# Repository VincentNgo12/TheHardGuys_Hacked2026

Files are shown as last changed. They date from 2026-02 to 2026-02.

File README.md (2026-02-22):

# NEST — Nursing Environment & Safety Tracker
### Smart Health Wristwatch

NEST is a **low-power ESP32 wristwatch prototype** designed for older adults or people that does not have the ability to take care of themselves.  
It helps users feel **safer, more comfortable, and more independent** by making key wellness and environment signals easy to check at a glance—without complicated menus or medical jargon.

**Our goal:** a reliable, power-efficient, hackathon-ready prototype with clean architecture and scalable code structure.

---

## Overview
This repository contains the **firmware and hardware design files** for our ESP32-based health + comfort wristwatch prototype.

**The system integrates:**
- **ESP32** (main MCU, low-power capable)
- **MAX30102** (heart rate / pulse sensing)
- **ENS160 + AHT21** (air quality + temperature + humidity)
- **MPU-6500** (motion sensing)
- **TFT LCD** (watch UI)

Firmware is built using the **Arduino framework**, but structured like a real embedded project:
- **Modular driver architecture** (each sensor isolated)
- **Cooperative FreeRTOS-style task design** (sensor polling, UI updates, Bluetooth, power management)

---

## High-level idea
NEST provides two kinds of awareness:

### 1) Health awareness
- Quick, on-demand **heart-rate checks** (simple “tap to check” experience)

### 2) Comfort awareness
- Indoor **temperature + humidity**
- **Air quality trends** (eCO2 / TVOC-style indicators)

**Design philosophy:** reassurance without overwhelm  
- big text, minimal taps  
- friendly labels + icons  
- clear prompts like: *“All good”*, *“Room feels stuffy”*, *“Take a break”*  
- optional gentle alerts (vibration) instead of loud alarms  

---

## System architecture (high-level)
NEST is organized as a clean pipeline so the UI stays responsive while keeping power low:

**Sensors → Drivers → Tasks/Scheduler → UI + Alerts → (Optional) Bluetooth**

A simple mental model:

| Layer | Components | Output |
|---|---|---|
| Sensors | MAX30102 • ENS160 + AHT21 • MPU-6500 | Raw readings |
| Driver Layer (modular) | Separate drivers per sensor | Standardized data |
| Task / Timing Layer | Polling • smoothing • thresholds • scheduling | Latest “status” + values |
| UI / Alerts | TFT Watch UI • Alerts/Bluetooth | On-screen info + vibration/summaries |

---

## Core concepts
### 1) Power-first behavior
NEST is designed around quick “check-ins”:
- measure briefly
- update the screen
- return to low-power mode whenever possible

A simple way to think about average power is:
\[
P_{\text{avg}} \approx \frac{P_{\text{active}}\,t_{\text{active}} + P_{\text{sleep}}\,t_{\text{sleep}}}{t_{\text{active}} + t_{\text{sleep}}}
\]
So the main strategy is keeping **\(t_{\text{active}}\)** short and spending most time sleeping.

### 2) Modular drivers
Each sensor is isolated in its own component so the project stays:
- easier to debug
- easier to test
- easier to expand later

### 3) Cooperative task design
Even when using Arduino, the project is structured to behave like a real embedded system:
- sensor reading doesn’t block UI updates  
- timing is predictable  
- Bluetooth/power management can be added cleanly  

---

## Repo structure
High-level folders (as included in this repository):
- `firmware/` — ESP32 firmware (Arduino-based, modular, task-oriented)
- `hardware/` — hardware design files (PCB / wiring / docs)
- `README.md` — this document

---

## Quick start (edit to match your setup)
1. Open `firmware/` in **Platform IO** 
2. Install required libraries for the display + sensors.
3. Select your ESP32 board, connect over USB, then **flash**.
4. Verify: UI boots, sensors respond, and readings update.

---

## Credits
**Team: The Hard Guys**  
- Vincent Ngo: damduchu@ualberta.ca
- Joao Pedro Assis Leitao: assislei@ualberta.ca
- Luu Gregory Nguyen: luugrego@ualberta.ca
- Jishnu Khanna: jkhanna@ualberta.ca
- Finhas Tadesse: finhas@ualberta.ca

Special thanks:
- UofA CompE club for organizing this amazing Hackathon
- Open-source libraries and community resources

---

## Disclaimer
NEST is a **hackathon prototype** intended for wellness/comfort awareness and is **not a medical device**.

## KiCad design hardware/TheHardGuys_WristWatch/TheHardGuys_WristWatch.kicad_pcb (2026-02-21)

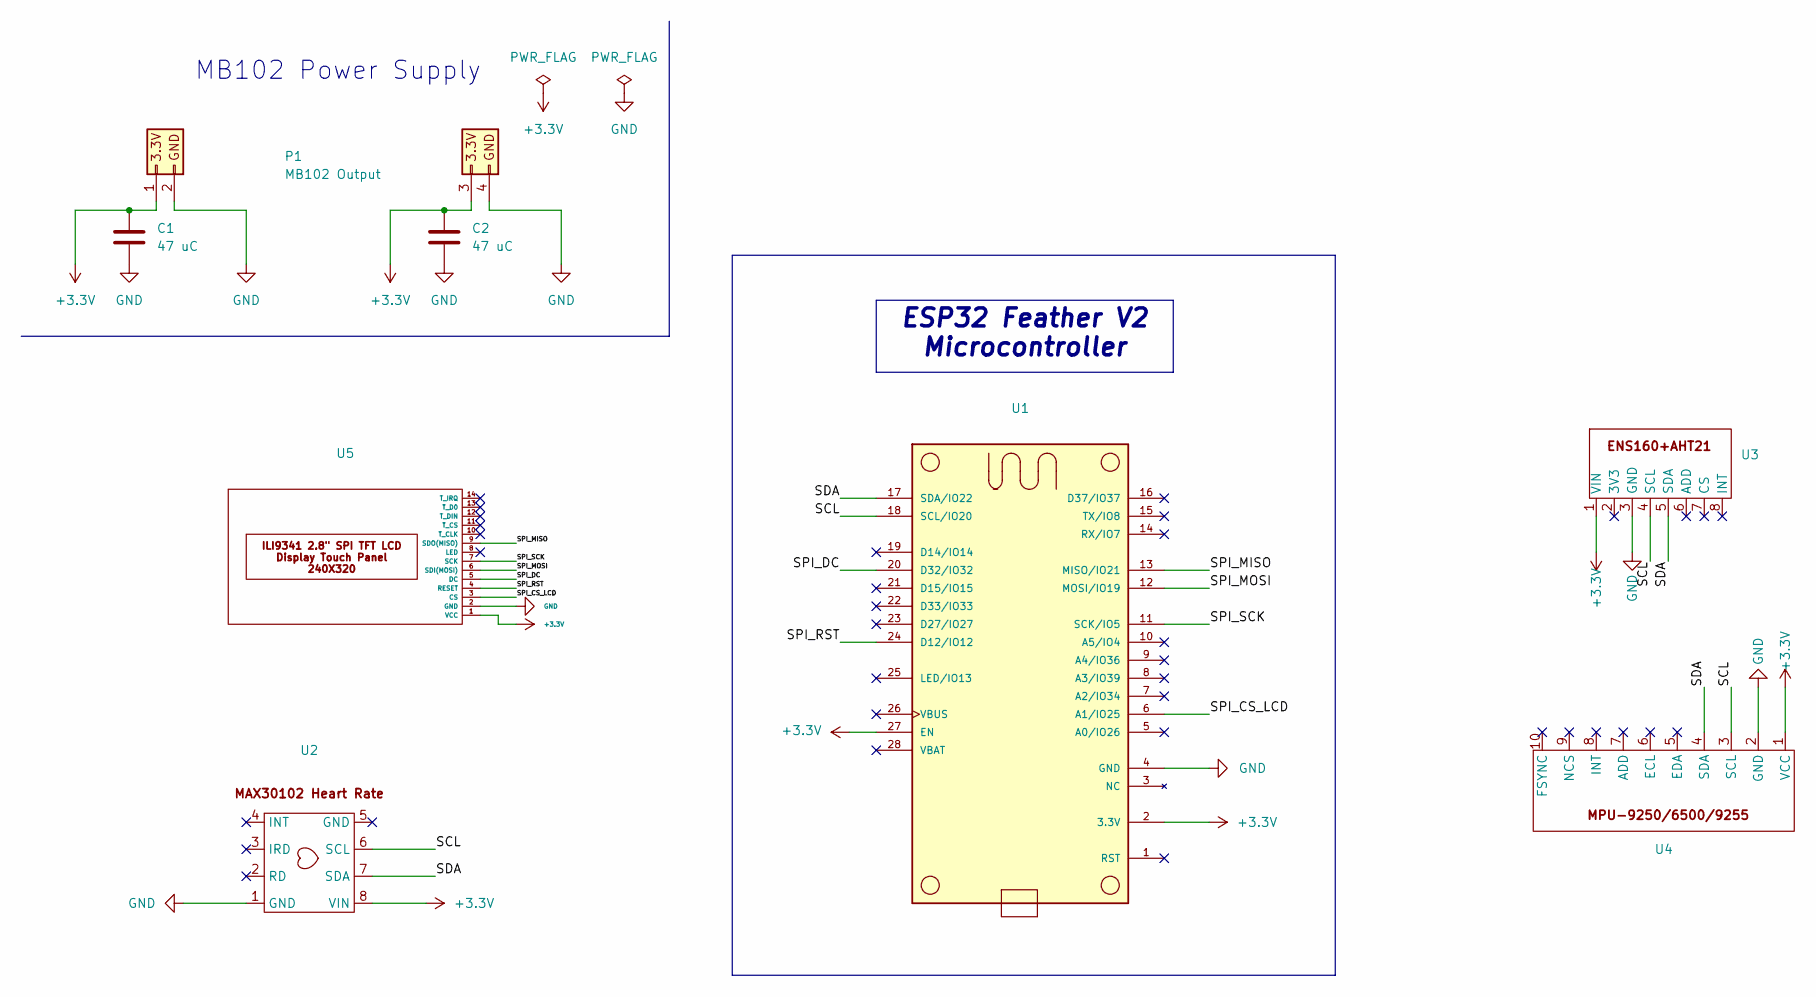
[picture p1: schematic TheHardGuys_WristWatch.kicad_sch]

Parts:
C1, C2: 47 uC; CP_Radial_D6.3mm_P2.50mm
P1: MB102 Output; MB102_Breadboard_Power_Module
U1: ESP32_Feather_V2
U2: MAX30102 Heart Rate_Pulse Sensor
U3: ENS160+AHT21_Environmental_Sensor
U4: MPU6500_IMU
U5: ILI9341_2.8__SPI_TFT_LCD

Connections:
+3.3V: C1.1, C2.1, P1.1 (3.3V), P1.3 (3.3V), U1.2 (3.3V), U1.27 (EN), U2.8 (VIN), U3.1 (VIN), U4.1 (VCC), U5.1 (VCC)
/SCL: U1.18 (SCL/IO20), U2.6 (SCL), U3.4 (SCL), U4.3 (SCL)
/SDA: U1.17 (SDA/IO22), U2.7 (SDA), U3.5 (SDA), U4.4 (SDA)
/SPI_CS_LCD: U1.6 (A1/IO25), U5.3 (CS)
/SPI_DC: U1.20 (D32/IO32), U5.5 (DC)
/SPI_MISO: U1.13 (MISO/IO21), U5.9 (SDO(MISO))
/SPI_MOSI: U1.12 (MOSI/IO19), U5.6 (SDI(MOSI))
/SPI_RST: U1.24 (D12/IO12), U5.4 (RESET)
/SPI_SCK: U1.11 (SCK/IO5), U5.7 (SCK)
GND: C1.2, C2.2, P1.2 (GND), P1.4 (GND), U1.4 (GND), U2.1 (GND), U3.3 (GND), U4.2 (GND), U5.2 (GND)

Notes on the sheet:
MB102 Power Supply
ESP32 Feather V2 Microcontroller

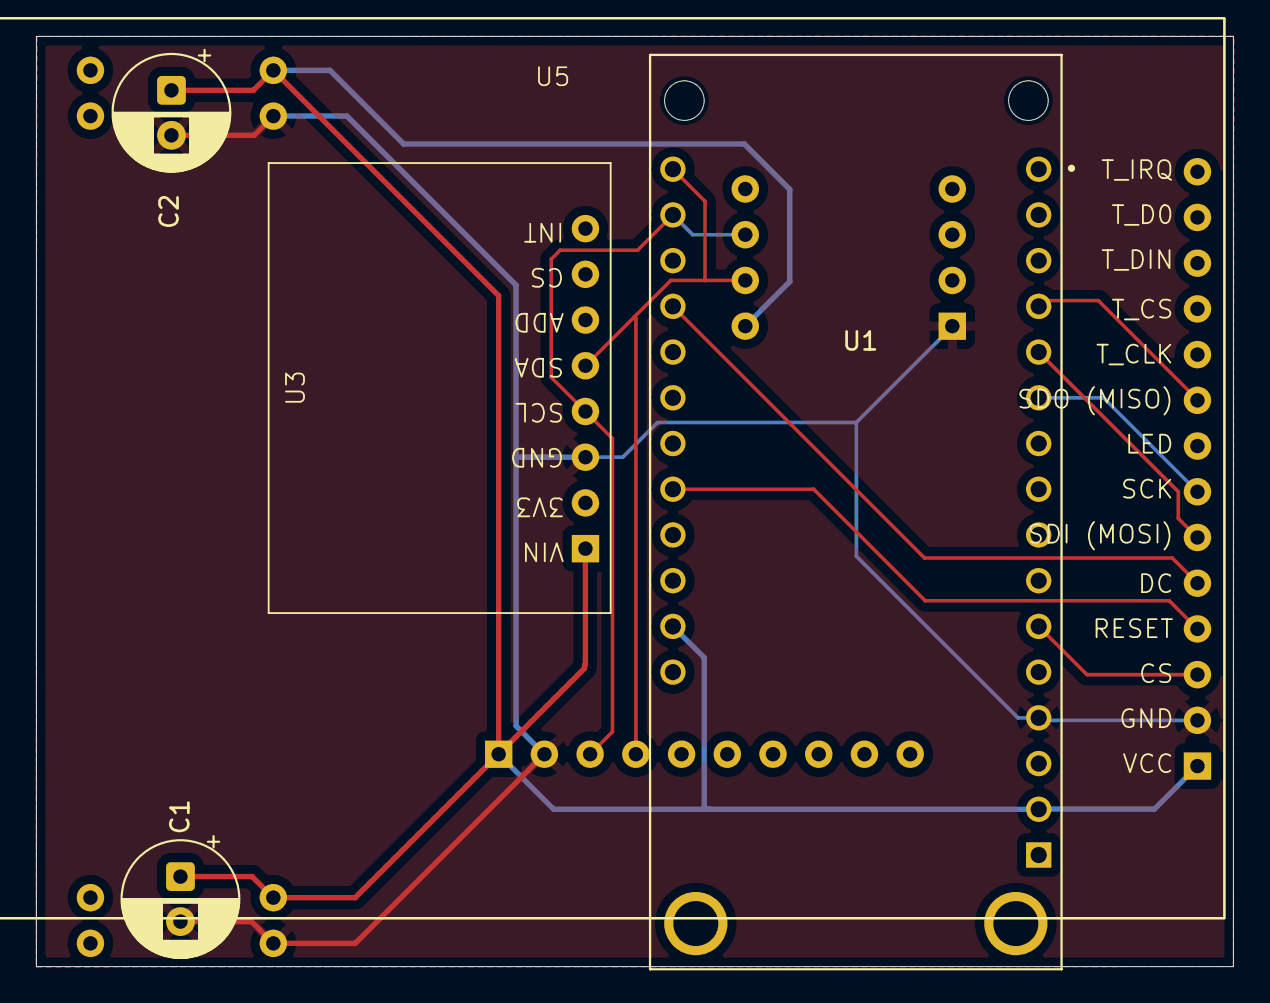
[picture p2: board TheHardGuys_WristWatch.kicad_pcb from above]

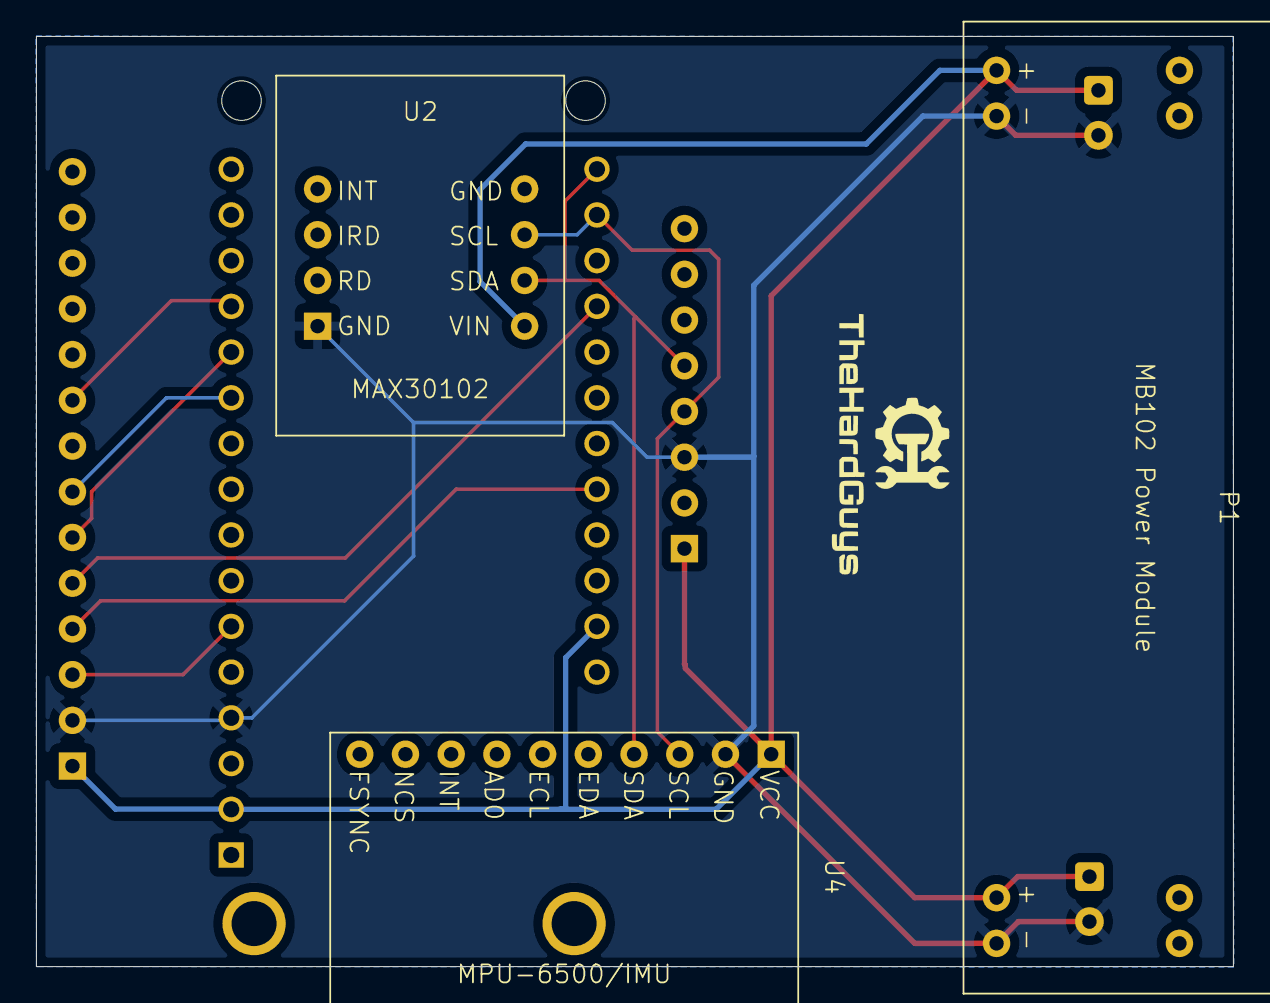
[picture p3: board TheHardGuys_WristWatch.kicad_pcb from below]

Board: 2 copper layers, 66.5 x 51.7 mm, 8 parts (3 on the bottom side), 10 nets.

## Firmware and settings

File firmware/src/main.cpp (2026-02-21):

// src/main.cpp
#include <Arduino.h>
#include <Wire.h>
#include "task_sensor.h"
#include "task_display.h"


void setup() {
    Serial.begin(115200);

    delay(2000); // extra settle time for serial debug only (remove in production code)

    Wire.begin(22, 20); // ESP32 Feather V2: SDA=22, SCL=20

    if (!sensorInit()) {
        Serial.println("Sensor init failed! Halting.");
        while (1);
    }

    Serial.println("All sensors initialized. Starting tasks...");

    if (!displayInit()) {
        Serial.println("Display init failed! Halting.");
        while (1);
    }

    Serial.println("=== All systems go ===");
}

void loop() {
    vTaskDelete(NULL);
}

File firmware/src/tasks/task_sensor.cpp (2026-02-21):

#include "task_sensor.h"
#include <Arduino.h>

// --------------------------------------------------
// Globals
// --------------------------------------------------
SensorData        g_sensorData = {};
SemaphoreHandle_t g_dataMutex  = nullptr;
SemaphoreHandle_t g_i2cMutex   = nullptr;

static AHT21Driver   aht21;
static ENS160Driver  ens160;
static MAX30102Driver max30102;
static MPU6500Driver mpu6500;

// --------------------------------------------------
// Forward declarations
// --------------------------------------------------
static void aht21Task   (void *pvParameters);
static void ens160Task  (void *pvParameters);
static void max30102Task(void *pvParameters);
static void mpu6500Task (void *pvParameters);

// --------------------------------------------------
// sensorInit — init all sensors + launch all tasks
// --------------------------------------------------
bool sensorInit() {
    g_dataMutex = xSemaphoreCreateMutex();
    g_i2cMutex  = xSemaphoreCreateMutex();

    if (!g_dataMutex || !g_i2cMutex) {
        Serial.println("[Sensor] Failed to create mutexes!");
        return false;
    }

    if (!aht21.begin()) {
        Serial.println("[Sensor] AHT21 not found!");
        return false;
    }
    Serial.println("[Sensor] AHT21 ready.");

    if (!ens160.begin()) {
        Serial.println("[Sensor] ENS160 not found!");
        return false;
    }
    Serial.println("[Sensor] ENS160 ready. Warming up...");

    if (!max30102.begin()) {
        Serial.println("[Sensor] MAX30102 not found!");
        return false;
    }
    Serial.println("[Sensor] MAX30102 ready.");

    if (!mpu6500.begin()) {
        Serial.println("[Sensor] MPU6500 not found!");
        return false;
    }
    Serial.println("[Sensor] MPU6500 ready.");

    // Launch all tasks here — main.cpp stays clean
    xTaskCreate(aht21Task,    "AHT21",    2048, NULL, 1, NULL);
    xTaskCreate(ens160Task,   "ENS160",   2048, NULL, 1, NULL);
    xTaskCreate(max30102Task, "MAX30102", 4096, NULL, 1, NULL); // larger stack, signal processing heavy
    xTaskCreate(mpu6500Task,  "MPU6500",  2048, NULL, 1, NULL);

    return true;
}

// --------------------------------------------------
// AHT21 Task — temp + humidity every 2s
// --------------------------------------------------
static void aht21Task(void *pvParameters) {
    while (true) {
        float temp, hum;

        if (xSemaphoreTake(g_i2cMutex, pdMS_TO_TICKS(500)) == pdTRUE) {
            bool ok = aht21.read(temp, hum);
            xSemaphoreGive(g_i2cMutex);

            if (ok) {
                if (xSemaphoreTake(g_dataMutex, pdMS_TO_TICKS(100)) == pdTRUE) {
                    g_sensorData.temperature = temp;
                    g_sensorData.humidity    = hum;
                    xSemaphoreGive(g_dataMutex);
                }
            } else {
                Serial.println("[AHT21] Read failed.");
            }
        }

        vTaskDelay(pdMS_TO_TICKS(2000));
    }
}

// --------------------------------------------------
// ENS160 Task — air quality every 2s
// Uses AHT21 temp+humidity for compensation
// --------------------------------------------------
static void ens160Task(void *pvParameters) {
    while (true) {
        // Grab latest AHT21 data for compensation
        float temp, hum;
        if (xSemaphoreTake(g_dataMutex, pdMS_TO_TICKS(100)) == pdTRUE) {
            temp = g_sensorData.temperature;
            hum  = g_sensorData.humidity;
            xSemaphoreGive(g_dataMutex);
        }

        uint16_t eco2, tvoc;
        int8_t   aqi;

        if (xSemaphoreTake(g_i2cMutex, pdMS_TO_TICKS(500)) == pdTRUE) {
            ens160.setCompensation(temp, hum);
            bool ok = ens160.read(eco2, tvoc, aqi);
            xSemaphoreGive(g_i2cMutex);

            if (ok) {
                if (xSemaphoreTake(g_dataMutex, pdMS_TO_TICKS(100)) == pdTRUE) {
                    g_sensorData.eco2        = eco2;
                    g_sensorData.tvoc        = tvoc;
                    g_sensorData.aqi         = aqi;

                    // Latch g_sensorData.ens160Ready to true once we get a real reading — never go back to false
                    if (!g_sensorData.ens160Ready && eco2 > 0) {
                        g_sensorData.ens160Ready = true;
                        Serial.println("[ENS160] Warm-up complete, data is valid.");
                    }

                    xSemaphoreGive(g_dataMutex);
                }
            } else {
                Serial.println("[ENS160] Read failed.");
            }
        }

        vTaskDelay(pdMS_TO_TICKS(2000));
    }
}

// --------------------------------------------------
// MAX30102 Task — heart rate + SpO2 every 100ms
// Faster poll rate — sensor needs continuous sampling
// --------------------------------------------------
static void max30102Task(void *pvParameters) {
    while (true) {
        float hr, spo2;
        bool  fingerDetected;

        if (xSemaphoreTake(g_i2cMutex, pdMS_TO_TICKS(500)) == pdTRUE) {
            bool ok = max30102.read(hr, spo2, fingerDetected);
            xSemaphoreGive(g_i2cMutex);

            if (ok) {
                if (xSemaphoreTake(g_dataMutex, pdMS_TO_TICKS(100)) == pdTRUE) {
                    g_sensorData.heartRate      = hr;
                    g_sensorData.spO2           = spo2;
                    g_sensorData.fingerDetected = fingerDetected;
                    xSemaphoreGive(g_dataMutex);
                }
            } else {
                Serial.println("[MAX30102] Read failed.");
            }
        }

        vTaskDelay(pdMS_TO_TICKS(100));
    }
}

// --------------------------------------------------
// MPU6500 Task — accel + gyro every 50ms
// --------------------------------------------------
static void mpu6500Task(void *pvParameters) {
    while (true) {
        float ax, ay, az;
        float gx, gy, gz;

        if (xSemaphoreTake(g_i2cMutex, pdMS_TO_TICKS(500)) == pdTRUE) {
            bool ok = mpu6500.read(ax, ay, az, gx, gy, gz);
            xSemaphoreGive(g_i2cMutex);

            if (ok) {
                if (xSemaphoreTake(g_dataMutex, pdMS_TO_TICKS(100)) == pdTRUE) {
                    g_sensorData.accelX = ax;
                    g_sensorData.accelY = ay;
                    g_sensorData.accelZ = az;
                    g_sensorData.gyroX  = gx;
                    g_sensorData.gyroY  = gy;
                    g_sensorData.gyroZ  = gz;
                    xSemaphoreGive(g_dataMutex);
                }
            } else {
                Serial.println("[MPU6500] Read failed.");
            }
        }

        vTaskDelay(pdMS_TO_TICKS(50));
    }
}

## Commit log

2026-02-21 Add all hardware design files (KiCAD, PCB design)
    [TheHardGuys_WristWatch.kicad_pcb, TheHardGuys_WristWatch.kicad_sch]
2026-02-21 Tries to write drivers for AHT21+ENS160; Didn't compile
    [main.cpp]
2026-02-21 Full Working State of Tested AHT21+ENS160 Sensors
2026-02-21 Working TFT Display with Prototype GUI
2026-02-21 Fixed the screen redraw issue a bit...
    [task_display.cpp]
